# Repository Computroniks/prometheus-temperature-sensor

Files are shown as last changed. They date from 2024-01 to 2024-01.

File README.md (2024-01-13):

<!-- 
SPDX-FileCopyrightText: 2023-2024 Sidings Media <contact@sidingsmedia.com>
SPDX-License-Identifier: MIT
-->

# Prometheus Temperature Sensor

A WiFi enabled temperature and humidity sensor built around an ESP8266
module with a Prometheus metrics endpoint.

## Hardware

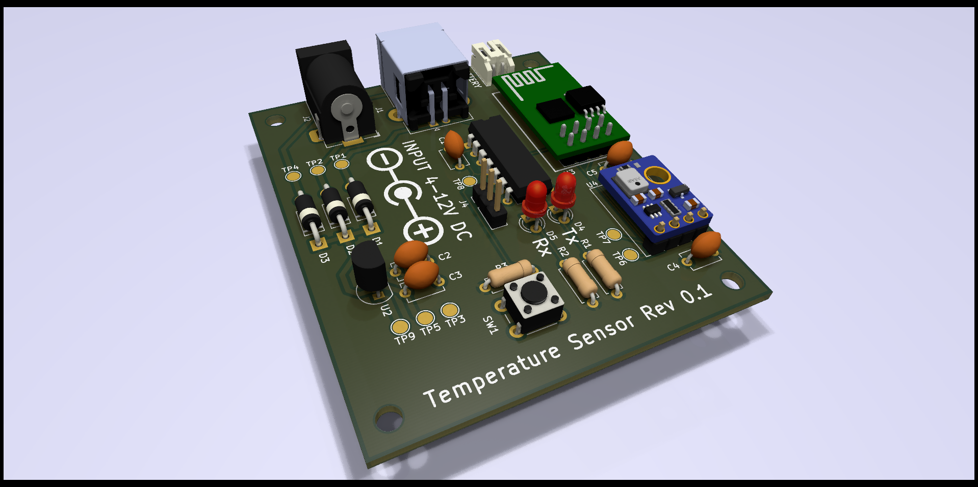
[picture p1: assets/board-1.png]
An image of Rev 0.1 of the PCB


The PCB is designed to be made with entirely through hole components to
make DIY assembly easy without having to mess around with fiddly SMD
components.

### Design

#### MCU

The ESP-01 module has been used to control the sensor. This is a small
module based upon the ESP8266. 

#### Temperature / Humidity Sensor

The temperature / humidity sensor that we have used for this design is
the AHT10 although any sensor that works with 3.3V and uses I2C could
probably be made to work.

#### Power

You can power the board in 3 different ways. There is a DC jack, a USB
connector (this also doubles as a serial interface for configuration)
and finally a JST battery connector to allow make the sensor portable.
All power inputs support from 4-12V DC. Power is regulated using a
MCP1702 low dropout regulator to minimize the voltage drop from power
input to the board power supply. Each input has a 1n5817 diode on the
positive input to prevent reverse powering of devices. This does also
induce a slight voltage drop so you may require a power supply slightly
above 4V, perhaps 4.5V.

### Design Software

The schematic and board design were both drawn using
[KiCad](https://www.kicad.org/), an open source electronic design
automation suite.

## Firmware

### Build Environment

#### Toolchain and SDK

You will need to setup both the toolchain for the ESP8266 as well as the
[ESP8266 RTOS SDK](https://github.com/espressif/ESP8266_RTOS_SDK).
Espressif provide documentation for the setup of both components.

* [Toolchain Setup](https://docs.espressif.com/projects/esp8266-rtos-sdk/en/latest/get-started/index.html#setup-toolchain)
* [SDK Setup](https://docs.espressif.com/projects/esp8266-rtos-sdk/en/latest/get-started/index.html#get-esp8266-rtos-sdk)

#### Environment Variables

Two environment variables are used to tell `esptool.py` (the tool used
by the SDK to flash your firmware to the ESP8266) where to flash to and
at what speed.

* `ESPPORT` - This is the path to the device to program, e.g.
  `/dev/ttyUSB0`.
* `ESPBAUD` - Baud rate to communicate at. Should normally be set to
  `115200` for flashing.

If you encounter an error such as below when running `make flash` you
probably need to set the `ESPPORT` environment variable.

```
A fatal error occurred: Cannot find target port named 'None'.
CMake Error at run_esptool.cmake:45 (message):
  esptool.py failed
```
#### Other requirements

You will also need CMake and Make installed to compile and flash the
firmware.

### Build and flash

#### Initialize build system

First create a build directory in src and cd into it.

```
mkdir build
cd build
```

Then you can run CMake to generate the build system.

```
cmake ../src
```

#### Compile and upload

To compile the firmware run:

```
make
```

And to upload to the board run:

```
make flash
```

`make flash` will also compile the firmware before it uploads it to the
board, so you can omit running `make` separately if you like.

## Licence
This repo uses the [REUSE](https://reuse.software) standard in order to
communicate the correct licence for the file. For those unfamiliar with
the standard the licence for each file can be found in one of three
places. The licence will either be in a comment block at the top of the
file, in a `.license` file with the same name as the file, or in the
dep5 file located in the `.reuse` directory. If you are unsure of the
licencing terms please contact
[mnickson@sidingsmedia.com](mailto:mnickson@sidingsmedia.com).
All files committed to this repo must contain valid licencing
information or the pull request can not be accepted.

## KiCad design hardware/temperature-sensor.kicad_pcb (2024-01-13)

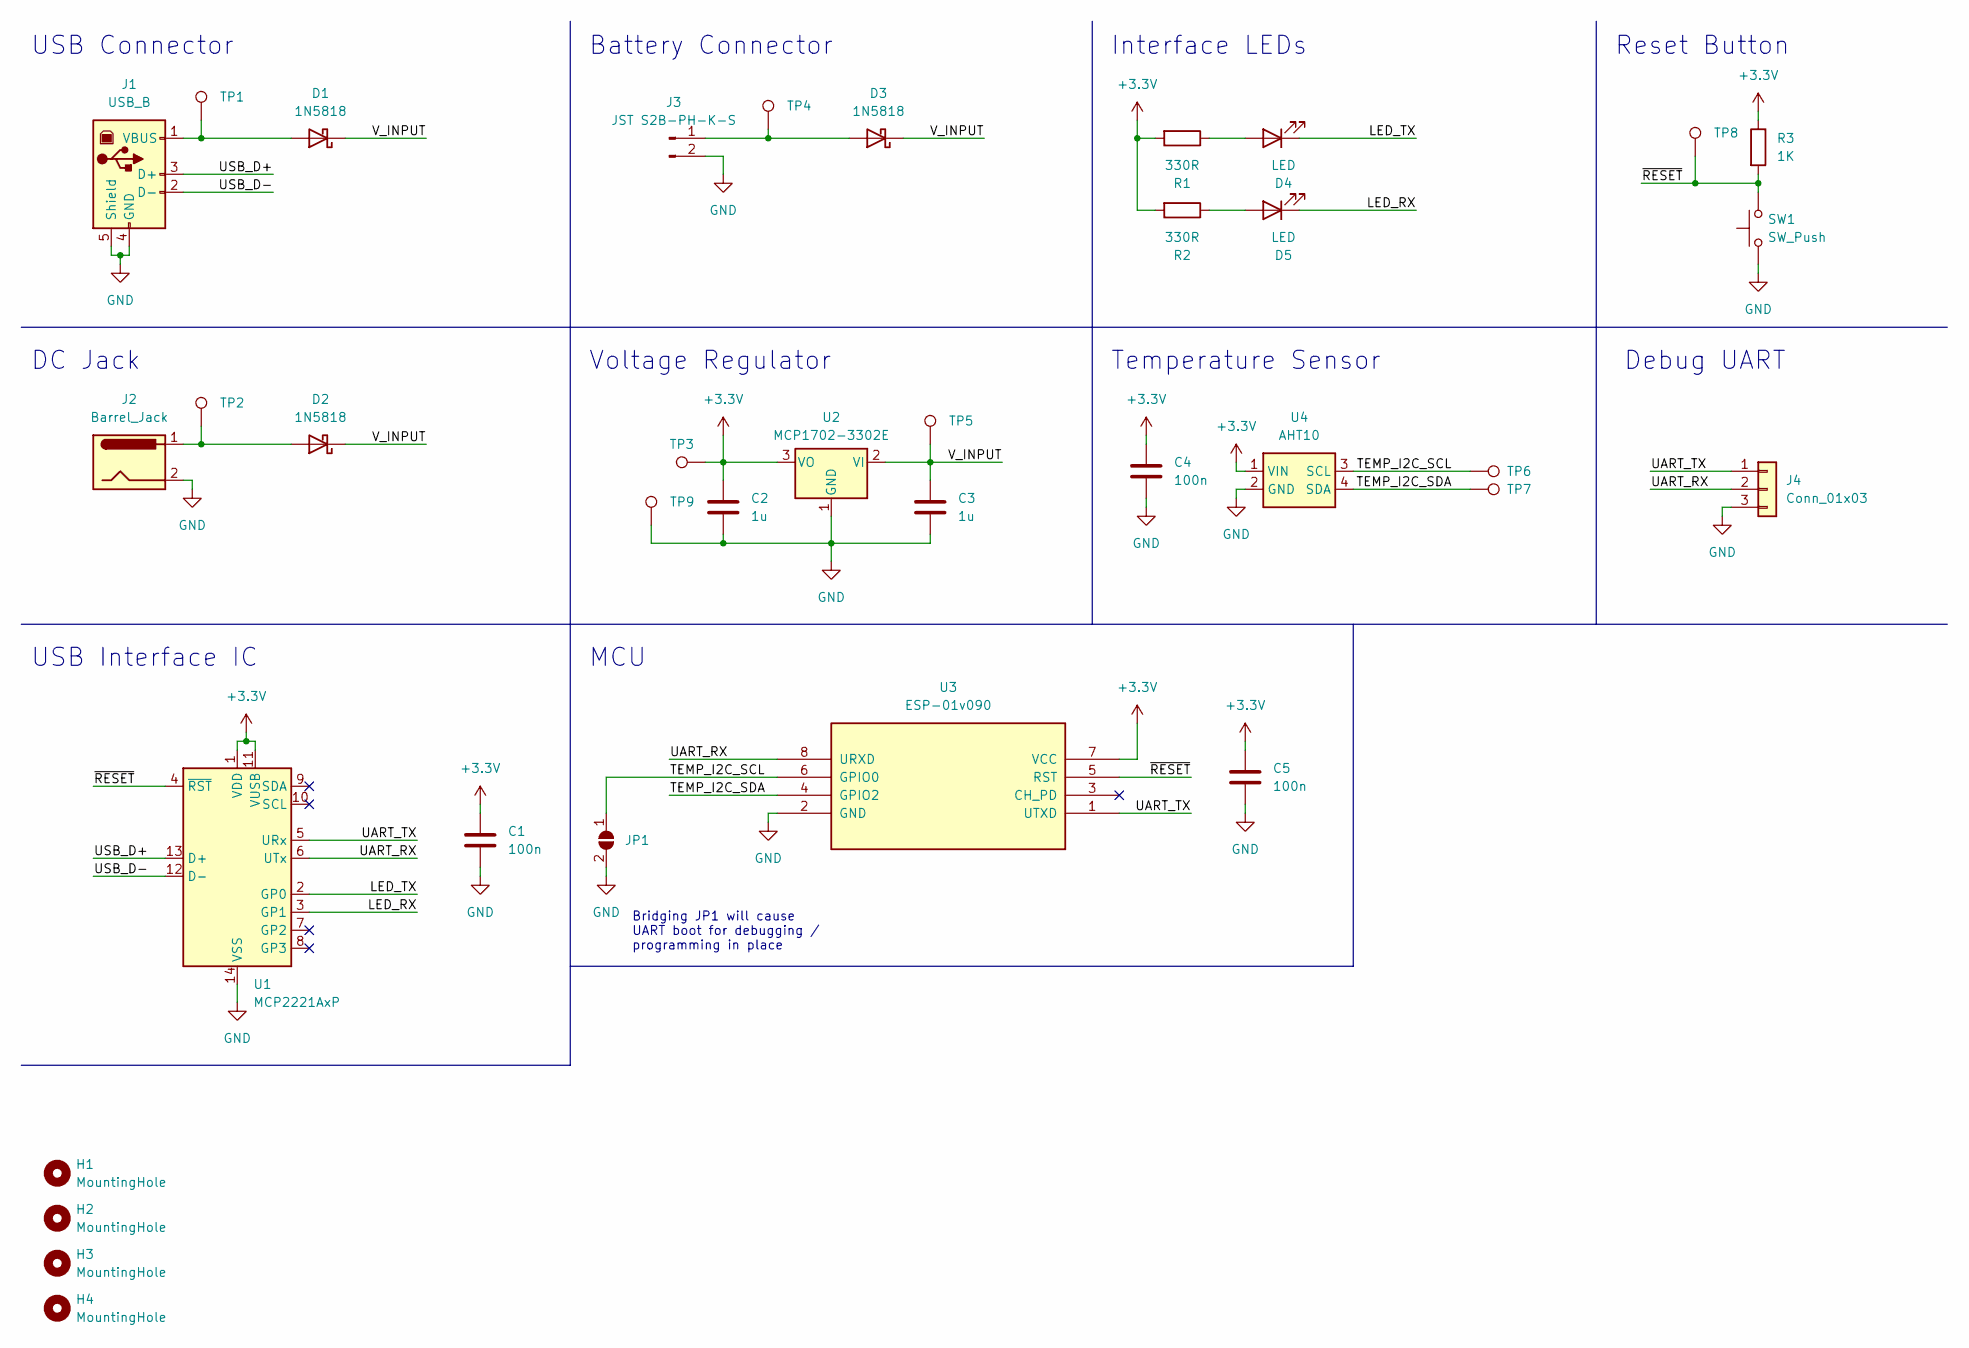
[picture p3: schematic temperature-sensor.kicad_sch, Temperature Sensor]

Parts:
C1, C4, C5: 100n; C_Disc_D5.1mm_W3.2mm_P5.00mm
C2, C3: 1u; C_Disc_D5.1mm_W3.2mm_P5.00mm
D1, D2, D3: 1N5818; D_DO-41_SOD81_P10.16mm_Horizontal
D4, D5: LED; LED_D3.0mm
H1, H2, H3, H4: MountingHole; MountingHole_3.2mm_M3
J1: USB_B; USB_B_Lumberg_2411_02_Horizontal
J2: Barrel_Jack; BarrelJack_Horizontal
J3: JST S2B-PH-K-S; JST_PH_S2B-PH-K_1x02_P2.00mm_Horizontal
J4: Conn_01x03; PinHeader_1x03_P2.54mm_Vertical
JP1: SolderJumper_2_Open; SolderJumper-2_P1.3mm_Open_Pad1.0x1.5mm
R1, R2: 330R; R_Axial_DIN0207_L6.3mm_D2.5mm_P7.62mm_Horizontal
R3: 1K; R_Axial_DIN0207_L6.3mm_D2.5mm_P7.62mm_Horizontal
SW1: SW_Push; SW_PUSH_6mm
TP1, TP2, TP3, TP4, TP5, TP6, TP7, TP8, TP9: TestPoint; TestPoint_Pad_D2.0mm
U1: MCP2221AxP; DIP-14_W7.62mm
U2: MCP1702-3302E; TO-92_Inline
U3: ESP-01v090; ESP-01
U4: AHT10

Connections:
+3.3V: C1.1, C2.1, C4.1, C5.1, R1.2, R2.2, R3.1, TP3.1, U1.1 (VDD), U1.11 (VUSB), U2.3 (VO), U3.7 (VCC), U4.1 (VIN)
/LED_RX: D5.1 (K), U1.3 (GP1)
/LED_TX: D4.1 (K), U1.2 (GP0)
/TEMP_I2C_SCL: JP1.1 (A), TP6.1, U3.6 (GPIO0), U4.3 (SCL)
/TEMP_I2C_SDA: TP7.1, U3.4 (GPIO2), U4.4 (SDA)
/UART_RX: J4.2, U1.6 (UTx), U3.8 (URXD)
/UART_TX: J4.1, U1.5 (URx), U3.1 (UTXD)
/USB_D+: J1.3 (D+), U1.13 (D+)
/USB_D-: J1.2 (D-), U1.12 (D-)
/V_INPUT: C3.1, D1.1 (K), D2.1 (K), D3.1 (K), TP5.1, U2.2 (VI)
/~RESET: R3.2, SW1.2, TP8.1, U1.4 (~RST), U3.5 (RST)
GND: C1.2, C2.2, C3.2, C4.2, C5.2, J1.4 (GND), J1.5 (Shield), J2.2, J3.2, J4.3, JP1.2 (B), SW1.1, TP9.1, U1.14 (VSS), U2.1 (GND), U3.2 (GND), U4.2 (GND)
unnamed: D1.2 (A), J1.1 (VBUS), TP1.1
unnamed: D2.2 (A), J2.1, TP2.1
unnamed: D3.2 (A), J3.1, TP4.1
unnamed: D4.2 (A), R1.1
unnamed: D5.2 (A), R2.1

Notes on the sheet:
Bridging JP1 will cause UART boot for debugging / programming in place
Debug UART
Battery Connector
USB Connector
Voltage Regulator
Reset Button
DC Jack
USB Interface IC
MCU
Interface LEDs
Temperature Sensor

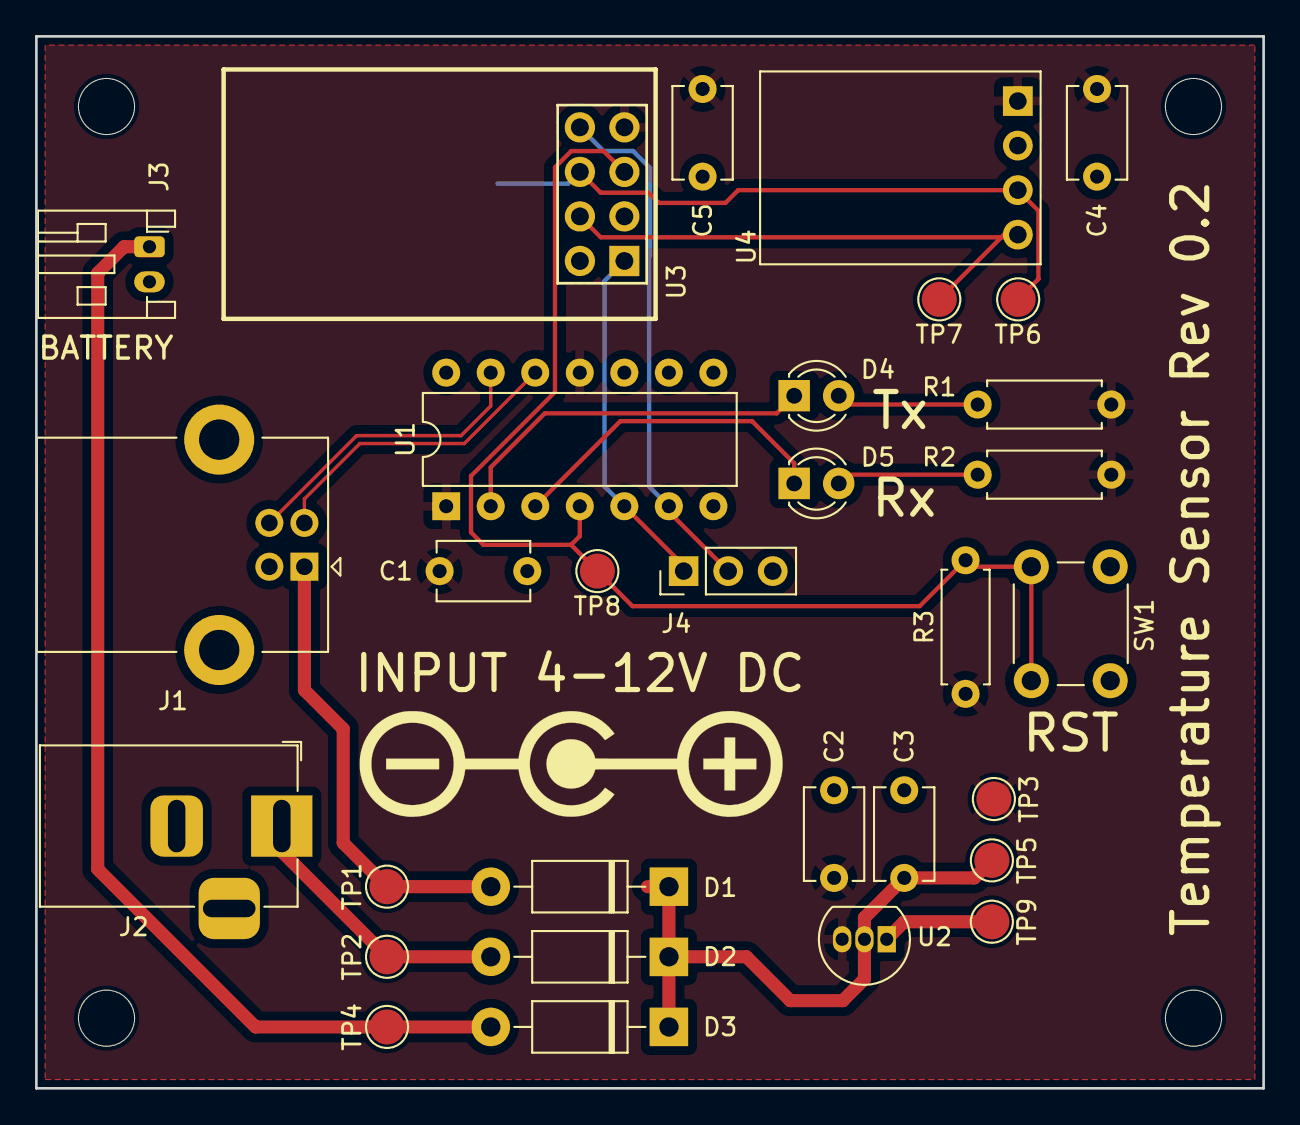
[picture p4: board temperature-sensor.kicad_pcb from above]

Board: 2 copper layers, 70.0 x 60.0 mm, 36 parts (1 on the bottom side), 17 nets.

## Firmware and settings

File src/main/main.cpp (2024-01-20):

// SPDX-FileCopyrightText: 2023-2024 Sidings Media <contact@sidingsmedia.com>
// SPDX-License-Identifier: MIT

#include "esp_log.h"
#include "esp_spi_flash.h"
#include "esp_system.h"
#include "esp_spiffs.h"

#include "freertos/FreeRTOS.h"
#include "freertos/task.h"
#include "sdkconfig.h"

#include "wlan.hpp"
#include "config/uart.hpp"
#include "sensor/aht10.hpp"
#include "webserver/server.hpp"

#define SPIFFS_MAX_FILES 4

static const char* TAG_ = "main";

void show_startup_info() {
    // Firmware info
    ESP_LOGI(TAG_, "%s %s", PROJECT_NAME, PROJECT_VERSION);
    ESP_LOGI(TAG_, "Compiled %s %s", __DATE__, __TIME__);
    ESP_LOGI(TAG_, "Repository %s", PROJECT_REPO);

    // IC Info
    esp_chip_info_t chip;
    esp_chip_info(&chip);
    ESP_LOGI(
        TAG_, "Model: %s",
        (chip.model == CHIP_ESP8266) ? "ESP8266" : "ESP32");
    ESP_LOGI(TAG_, "Silicon revision: %d", chip.revision);
    ESP_LOGI(TAG_, "Cores: %d", chip.cores);
    ESP_LOGI(TAG_, "Crystal: %dMHz", CRYSTAL_USED);

    // Chip features
    ESP_LOGI(TAG_, "Features:");
    ESP_LOGI(
        TAG_, "Embedded flash: %s",
        (chip.features & CHIP_FEATURE_EMB_FLASH) ? "Yes" : "No");
    ESP_LOGI(
        TAG_, "2.4GHz WiFi: %s",
        (chip.features & CHIP_FEATURE_WIFI_BGN) ? "Yes" : "No");
    ESP_LOGI(
        TAG_, "Bluetooth LE: %s",
        (chip.features & CHIP_FEATURE_BLE) ? "Yes" : "No");
    ESP_LOGI(
        TAG_, "Bluetooth Classic: %s",
        (chip.features & CHIP_FEATURE_BT) ? "Yes" : "No");

    // MAC addresses
    unsigned char mac[8];
    esp_efuse_mac_get_default(mac);
    ESP_LOGI(
        TAG_, "MAC Address: %02x:%02x:%02x:%02x:%02x:%02x",
        mac[0], mac[1], mac[2], mac[3], mac[4], mac[5]);

    // Flash Info
    ESP_LOGI(
        TAG_, "%dMB %s flash",
        spi_flash_get_chip_size() / (1024 * 1024),
        (chip.features & CHIP_FEATURE_EMB_FLASH) ? "embedded" : "external");
}

esp_err_t init_spiffs() {
    ESP_LOGI(TAG_, "Initialising SPIFFS file system");

    esp_vfs_spiffs_conf_t conf = {
        .base_path = "/spiffs",
        .partition_label = NULL,
        .max_files = SPIFFS_MAX_FILES,
        .format_if_mount_failed = true,
    };

    esp_err_t ret = esp_vfs_spiffs_register(&conf);
    if (ret != ESP_OK) {
        switch (ret) {
        case ESP_FAIL:
            ESP_LOGE(TAG_, "ESP_FAIL: Failed to mount or format file system");
            break;
        case ESP_ERR_NOT_FOUND:
            ESP_LOGE(TAG_, "ESP_ERR_NOT_FOUND: Could not find SPIFFS partition");
            break;
        default:
            ESP_LOGE(TAG_, "Failed to initialise SPIFFS (%s)", esp_err_to_name(ret));
            break;
        }
        return ret;
    }

    size_t total = 0, used = 0;
    ret = esp_spiffs_info(NULL, &total, &used);
    if (ret != ESP_OK) {
        ESP_LOGE(TAG_, "Failed to get SPIFFS partition information (%s)", esp_err_to_name(ret));
        return ret;
    }

    {
        ESP_LOGI(TAG_, "Partition size: total: %d, used: %d", total, used);
    }

    return ESP_OK;
}

void uart_task(void* arg) {
    AHT10* sensor = (AHT10*)arg;
    UART uart = UART(74800, sensor);
    uart.Listen();
}

extern "C" void app_main() {
    show_startup_info();
    init_spiffs();

    AHT10 sensor = AHT10(GPIO_NUM_0, GPIO_NUM_2, I2C_NUM_0, 0x38);
    // Start UART command handler first after initial startup
    xTaskCreate(uart_task, "uart_listen", 2048, &sensor, 10, NULL);

    network_init();
    // Server server = Server(80, &sensor);
    webserver_start(80, &sensor);
    // server.Listen();
}

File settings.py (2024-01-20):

# SPDX-FileCopyrightText: 2024 Sidings Media <contact@sidingsmedia.com>
# SPDX-License-Identifier: MIT
"""
Serial tool to modify settings of temp sensor
"""

from enum import Enum
import struct

import click
import serial

class Commands(Enum):
    UART_CMD_RESET = b"\x01"
    UART_CMD_CONFIG_SET_WIFI_SSID = b"\x11"
    UART_CMD_CONFIG_GET_WIFI_SSID = b"\x12"
    UART_CMD_CONFIG_SET_WIFI_KEY = b"\x13"
    UART_CMD_CONFIG_CLEAR_WIFI = b"\x14"
    UART_CMD_SENSOR_GET_TEMP = b"\x20"
    UART_CMD_SENSOR_GET_HUMIDITY = b"\x21"
    UART_CMD_SYS_GET_UPTIME = b"\x30"


class Err(Enum):
    UART_ERR_OK = b"\x00"
    UART_ERR_FAIL = b"\x01"
    UART_ERR_DISABLED = b"\x02"
    UART_ERR_INVALID_CMD = b"\x03"
    UART_ERR_INVALID_VALUE = b"\x04"
    UART_ERR_NOT_IMPLEMENTED = b"\x05"


def _read(conn: serial.Serial, size: int):
    """
    _read Read response ignoring log statements
    """

    while (True):
        data = conn.read(1)
        log_values = [b"D", b"I", b"W", b"E"]
        if data in log_values:
            log = (data + conn.read_until(b"\n")).decode()
            print(log, end="")
        else:
            left_to_read = size - 1
            if size != 0:
                data += conn.read(left_to_read)
            return data


@click.group()
@click.option("--port", help="Port temp sensor is connected to.", required=True)
@click.option("--baud", help="Baud rate to connect at.", default=74880)
@click.pass_context
def cli(ctx, port: str, baud: int):
    ctx.ensure_object(dict)

    ctx.obj["port"] = port
    ctx.obj["baud"] = baud


@cli.command("clear-wifi-conf")
@click.pass_context
def clear_wifi_conf(ctx):
    buf = bytearray()
    buf.extend(Commands.UART_CMD_CONFIG_CLEAR_WIFI.value)

    conn = serial.Serial(ctx.obj["port"], ctx.obj["baud"])
    conn.write(buf)
    res = _read(conn, 1)
    click.echo(Err(res).name)


@cli.command("get-temp")
@click.pass_context
def get_temp(ctx):
    buf = bytearray()
    buf.extend(Commands.UART_CMD_SENSOR_GET_TEMP.value)

    conn = serial.Serial(ctx.obj["port"], ctx.obj["baud"])
    conn.write(buf)
    temp = _read(conn, 4)
    click.echo(struct.unpack("f", temp)[0])
    res = _read(conn, 1)
    click.echo(Err(res).name)


@cli.command("get-humidity")
@click.pass_context
def get_humidity(ctx):
    buf = bytearray()
    buf.extend(Commands.UART_CMD_SENSOR_GET_HUMIDITY.value)

    conn = serial.Serial(ctx.obj["port"], ctx.obj["baud"])
    conn.write(buf)
    humidity = _read(conn, 4)
    click.echo(struct.unpack("f", humidity)[0])
    res = _read(conn, 1)
    click.echo(Err(res).name)

@cli.command("get-uptime", help="Get system uptime in seconds")
@click.pass_context
def get_uptime(ctx):
    buf = bytearray()
    buf.extend(Commands.UART_CMD_SYS_GET_UPTIME.value)

    conn = serial.Serial(ctx.obj["port"], ctx.obj["baud"])
    conn.write(buf)
    uptime = _read(conn, 8)
    uptime = struct.unpack("q", uptime)[0]
    click.echo(uptime / (1000*1000))
    res = _read(conn, 1)
    click.echo(Err(res).name)



@cli.command()
@click.pass_context
def reset(ctx):
    buf = bytearray()
    buf.extend(Commands.UART_CMD_RESET.value)

    conn = serial.Serial(ctx.obj["port"], ctx.obj["baud"])
    conn.write(buf)
    

if __name__ == "__main__":
    cli(obj={})

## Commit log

2024-01-08 Initial hardware design
    [temperature-sensor.kicad_pcb, temperature-sensor.kicad_sch]
2024-01-12 Added correct 3D models
    [temperature-sensor.kicad_pcb]
2024-01-13 Rev 0.2 - Added jumper to support UART boot
    [temperature-sensor.kicad_pcb, temperature-sensor.kicad_sch]
2024-01-13 Fixed fab references
    [temperature-sensor.kicad_pcb, temperature-sensor.kicad_sch]
2024-01-13 Separated I2C tracks
    [temperature-sensor.kicad_pcb]
2024-01-13 Enabled SPIFFS filesystem
    [partitions.csv]
2024-01-16 Added initial config setting via UART
    Not quite complete yet though as still some issues with setting wifi
    [main.cpp, settings.py, uart.cpp]
2024-01-18 Fixed UART update wifi settings
    [main.cpp, settings.py, uart.cpp]
2024-01-20 Fixed partition size
    [partitions.csv]
2024-01-20 Added UART commands for new provisioning
2024-01-20 Added provision for multiple access to sensor
2024-01-20 Fixed sensor not being released after measure
    [aht10.cpp]
2024-01-20 Enabled sensor access through UART
2024-01-20 Enabled get uptime from UART
2024-01-21 Slight improvements to error handling
    [aht10.cpp]

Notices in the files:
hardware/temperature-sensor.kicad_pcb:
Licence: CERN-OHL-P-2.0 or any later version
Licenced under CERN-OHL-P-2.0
